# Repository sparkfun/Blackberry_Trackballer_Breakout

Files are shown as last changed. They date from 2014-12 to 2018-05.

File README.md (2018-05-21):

**NOTE:** *This product has been retired from our catalog. If you are looking for more up-to-date info, please check out some of these resources to see how other users are still hacking and improving on this product.*
* *[SparkFun Forum](https://forum.sparkfun.com/)*
* *[Comments Here on GitHub](https://github.com/sparkfun/Blackberry_Trackballer_Breakout/issues)*
* *[IRC Channel](https://www.sparkfun.com/news/263)*

SparkFun BlackBerry Trackballer Breakout
========================================

SparkFun BlackBerry Trackballer Breakout

[*SparkFun BlackBerry Trackballer Breakout (COM-13169)*](https://www.sparkfun.com/products/13169)

The SparkFun BlackBerry Trackballer Breakout gives you easy access to a trackball which measures up, down, left, and right movements, clicks on the board, as well as adding a bit of flair to your project with four built-in LEDs. The trackballer breakout can be hooked into an Arduino compatible device to provide you with an intuitive direction controller.

Repository Contents
-------------------
 
* **/Firmware** - Example Arduino code 
* **/Hardware** - Eagle design files (.brd, .sch) for the main PCB, and the mounting PCB. 
* **/Production** - Production panel files (.brd) for the main PCB. The mounting PCB did not need to be panelized. 

Documentation
--------------
* **[Hookup Guide](https://learn.sparkfun.com/tutorials/blackberry-trackballer-breakout-hookup-guide)** - Basic hookup guide for the Trackballer Breakout.
* **[SparkFun Fritzing repo](https://github.com/sparkfun/Fritzing_Parts)** - Fritzing diagrams for SparkFun products.
* **[SparkFun 3D Model repo](https://github.com/sparkfun/3D_Models)** - 3D models of SparkFun products. 

Product Versions
----------------
* [COM-13169](https://www.sparkfun.com/products/13169)- Version 1.3. Retired.
* [COM-09320](https://www.sparkfun.com/products/9320)- Version 1.2. Retired. 

License Information
-------------------
This product is _**open source**_! 

The **hardware** is released under [Creative Commons ShareAlike 4.0 International](https://creativecommons.org/licenses/by-sa/4.0/).

The **code** is beerware; if you see me (or any other SparkFun employee) at the local, and you've found our code helpful, please buy us a round!

Please use, reuse, and modify these files as you see fit. Please maintain attribution to SparkFun Electronics and release anything derivative under the same license.

Distributed as-is; no warranty is given.

- Your friends at SparkFun.

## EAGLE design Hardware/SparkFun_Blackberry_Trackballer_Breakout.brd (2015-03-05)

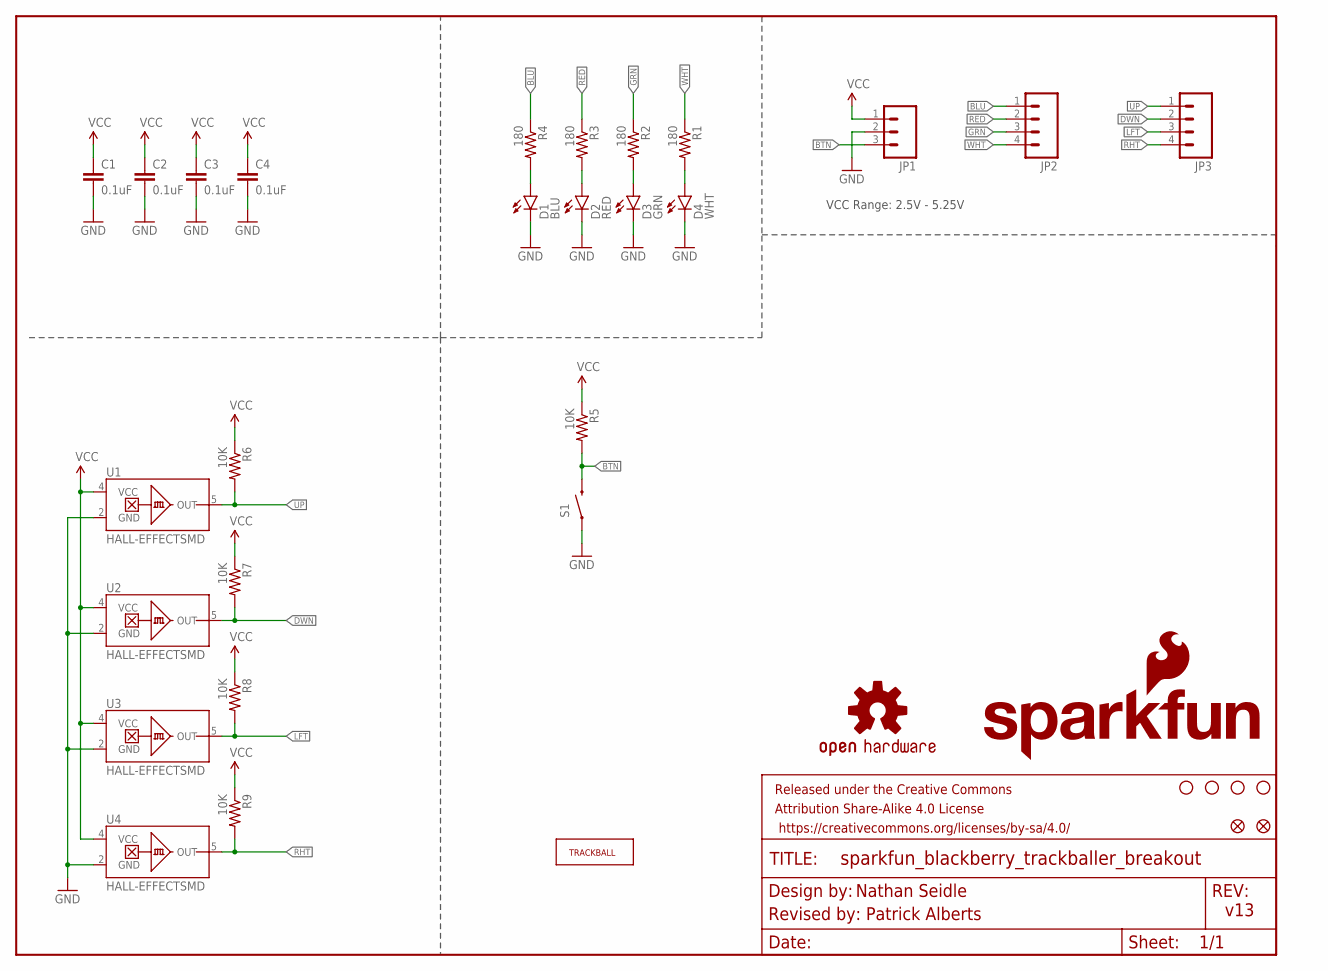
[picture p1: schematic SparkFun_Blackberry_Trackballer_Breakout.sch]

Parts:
C1, C2, C3, C4: 0.1uF; 0603-CAP
D1: BLU; LED-0603
D2: RED; LED-0603
D3: GRN; LED-0603
D4: WHT; LED-0603
E$1, E$2: FIDUCIAL1X2; FIDUCIAL-1X2
FRAME1: FRAME-LETTER; CREATIVE_COMMONS
JP1: M03PTH; 1X03
JP2, JP3: M04PTH; 1X04
LOGO1: SFE_LOGO_NAME_FLAME.2_INCH; SFE_LOGO_NAME_FLAME_.2
LOGO2: OSHW-LOGOS; OSHW-LOGO-S
R1, R2, R3, R4: 180; 0603-RES
R5, R6, R7, R8, R9: 10K; 0603-RES
S1: SWITCH-MOMENTARY-2SMD-2; TACTILE_SWITCH_SMD-2
U1, U2, U3, U4: HALL-EFFECTSMD; SC70
U$1, U$8, U$11, U$14: STAND-OFF
U$3: TRACKBALLMECH; TRACKBALL

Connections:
BLU: JP2.1, R4.1
BTN: JP1.3, R5.2, S1.1 (2)
DWN: JP3.2, R7.2, U2.5 (OUT)
GND: C1.2, C2.2, C3.2, C4.2, D1.C, D2.C, D3.C, D4.C, JP1.2, S1.2 (1), U1.2 (GND), U2.2 (GND), U3.2 (GND), U4.2 (GND)
GRN: JP2.3, R2.1
LFT: JP3.3, R8.2, U3.5 (OUT)
unnamed: D3.A, R2.2
unnamed: D2.A, R3.2
unnamed: D1.A, R4.2
unnamed: D4.A, R1.2
RED: JP2.2, R3.1
RHT: JP3.4, R9.2, U4.5 (OUT)
UP: JP3.1, R6.2, U1.5 (OUT)
VCC: C1.1, C2.1, C3.1, C4.1, JP1.1, R5.1, R6.1, R7.1, R8.1, R9.1, U1.4 (VCC), U2.4 (VCC), U3.4 (VCC), U4.4 (VCC)
WHT: JP2.4, R1.1

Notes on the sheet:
v13
Nathan Seidle
Revised by: Patrick Alberts
VCC Range: 2.5V - 5.25V

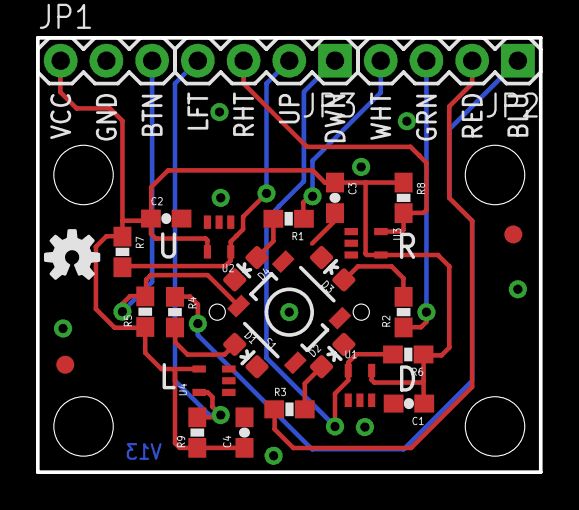
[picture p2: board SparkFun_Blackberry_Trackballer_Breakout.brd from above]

Board: 2 copper layers, 27.9 x 24.1 mm, 35 parts (1 on the bottom side), 15 nets.

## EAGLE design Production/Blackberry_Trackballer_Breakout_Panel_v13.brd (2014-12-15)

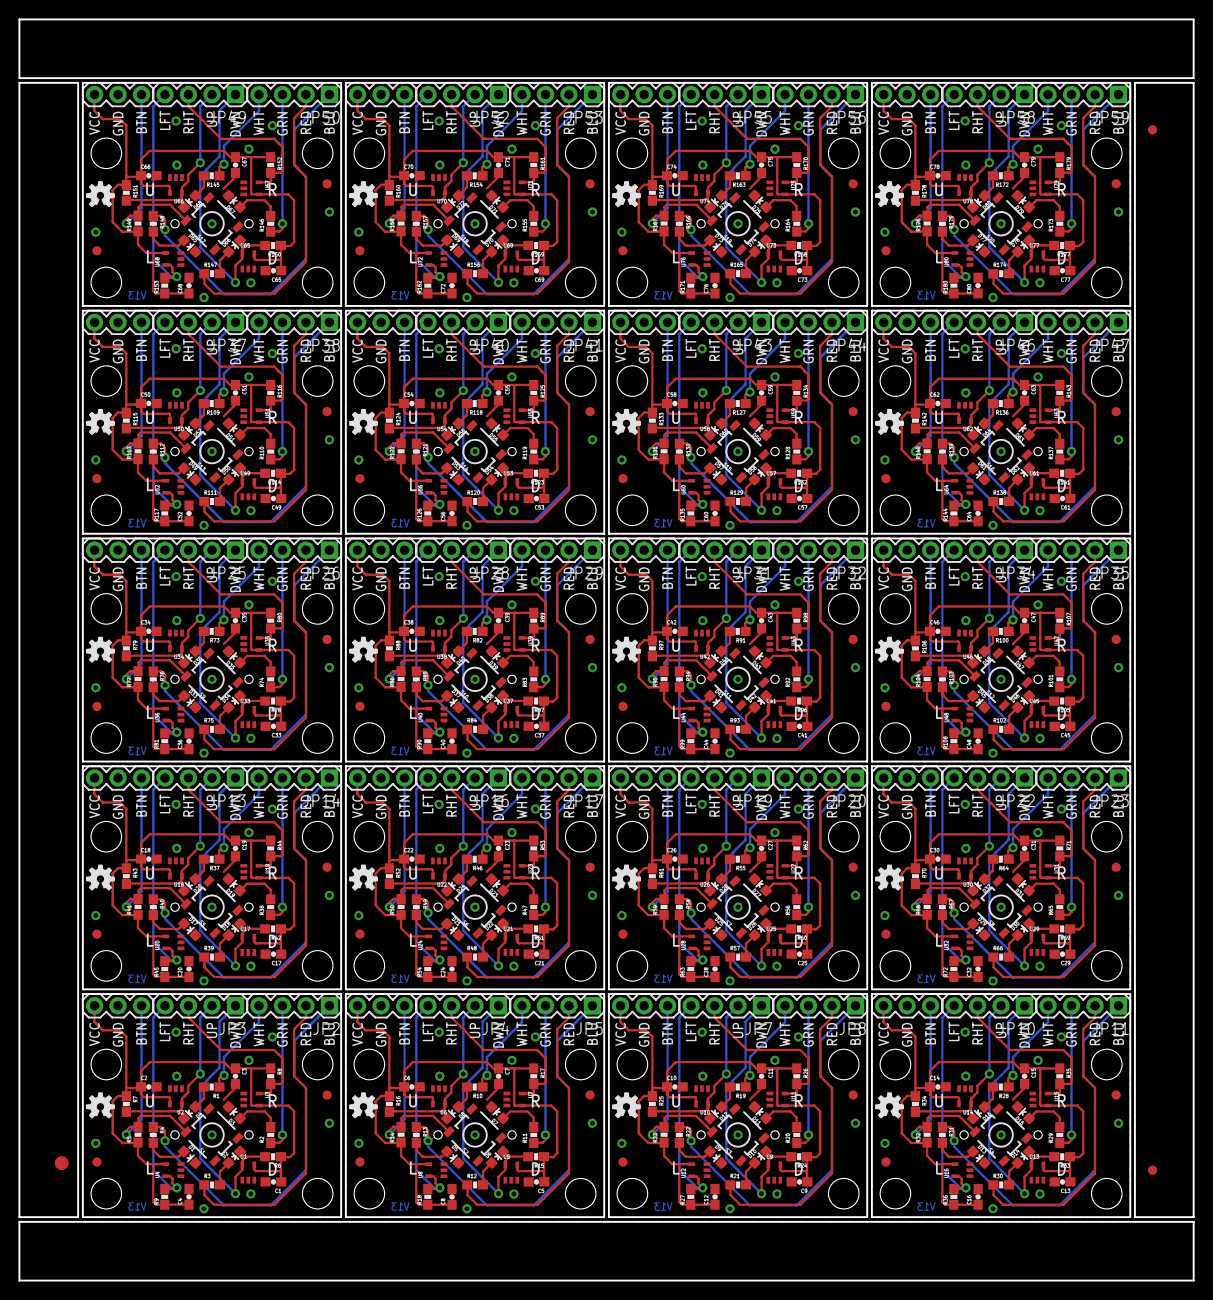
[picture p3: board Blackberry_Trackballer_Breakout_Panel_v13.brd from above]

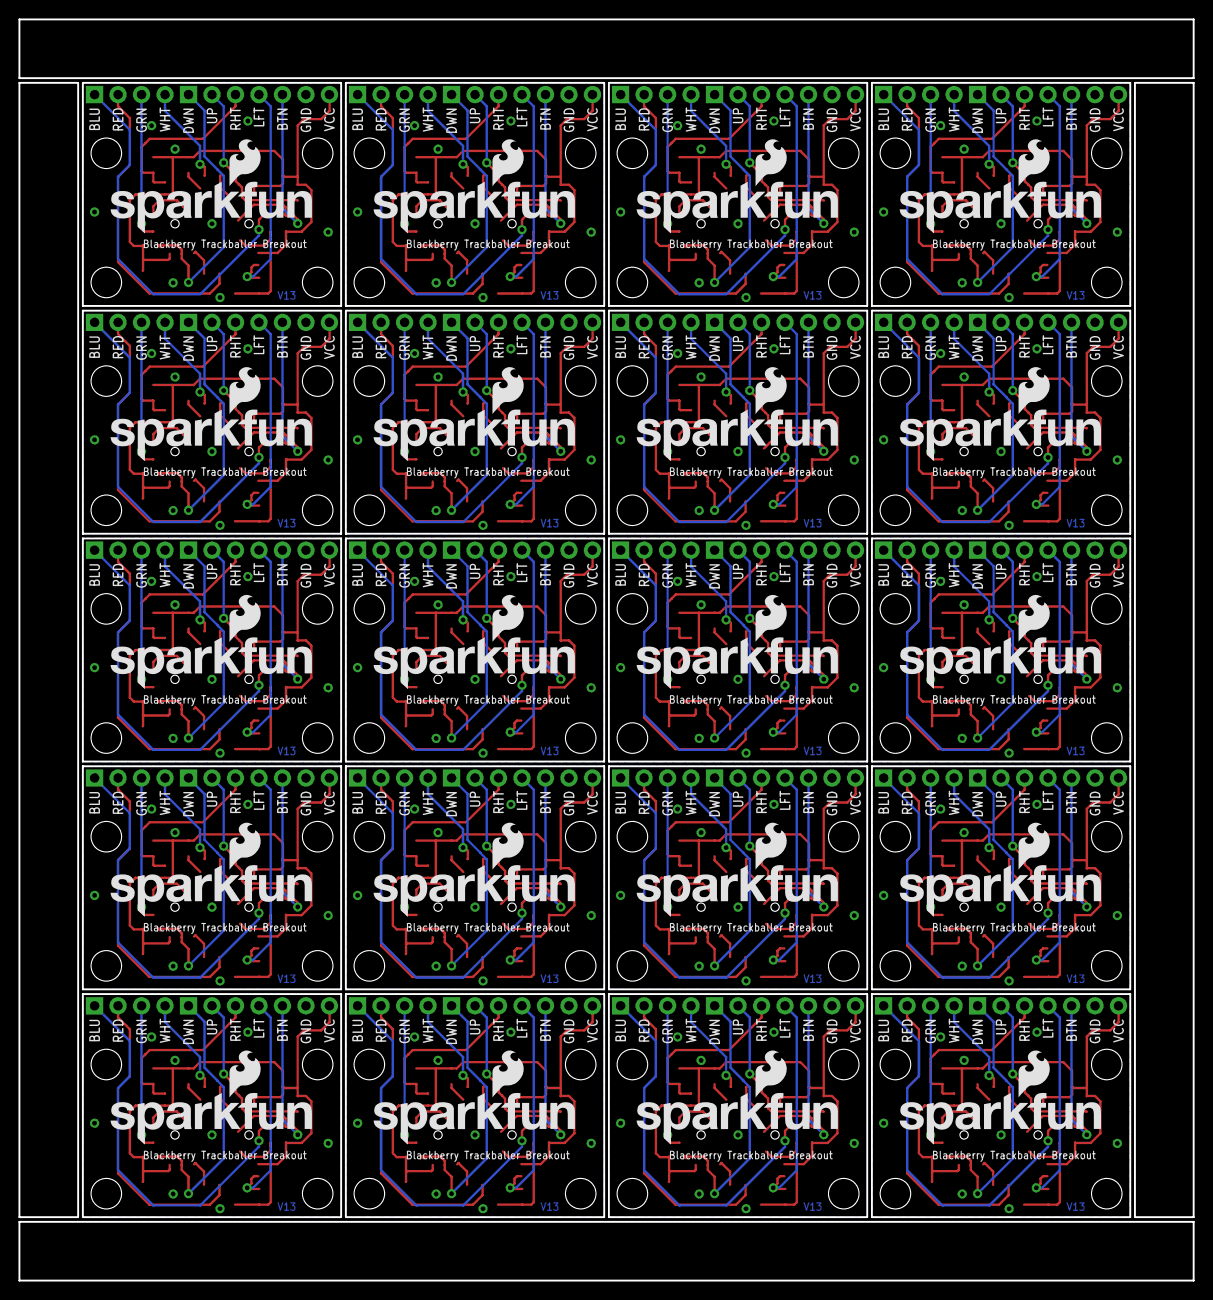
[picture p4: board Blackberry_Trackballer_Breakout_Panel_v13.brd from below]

Board: 2 copper layers, 127.0 x 136.4 mm, 683 parts (20 on the bottom side), 300 nets.

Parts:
C1, C2, C3, C4, C5, C6, C7, C8, C9, C10, C11, C12, C13, C14, C15, C16, C17, C18, C19, C20, C21, C22, C23, C24, C25, C26, C27, C28, C29, C30, C31, C32, C33, C34, C35, C36, C37, C38, C39, C40, C41, C42, C43, C44, C45, C46, C47, C48, C49, C50, C51, C52, C53, C54, C55, C56, C57, C58, C59, C60, C61, C62, C63, C64, C65, C66, C67, C68, C69, C70, C71, C72, C73, C74, C75, C76, C77, C78, C79, C80: 0.1uF; 0603-CAP
D1, D5, D9, D13, D17, D21, D25, D29, D33, D37, D41, D45, D49, D53, D57, D61, D65, D69, D73, D77: BLU; LED-0603
D2, D6, D10, D14, D18, D22, D26, D30, D34, D38, D42, D46, D50, D54, D58, D62, D66, D70, D74, D78: RED; LED-0603
D3, D7, D11, D15, D19, D23, D27, D31, D35, D39, D43, D47, D51, D55, D59, D63, D67, D71, D75, D79: GRN; LED-0603
D4, D8, D12, D16, D20, D24, D28, D32, D36, D40, D44, D48, D52, D56, D60, D64, D68, D72, D76, D80: WHT; LED-0603
E$1, E$2, E$3, E$4, E$5, E$6, E$7, E$8, E$9, E$10, E$11, E$12, E$13, E$14, E$15, E$16, E$17, E$18, E$19, E$20, E$21, E$22, E$23, E$24, E$25, E$26, E$27, E$28, E$29, E$30, E$31, E$32, E$33, E$34, E$35, E$36, E$37, E$38, E$39, E$40: FIDUCIAL1X2; FIDUCIAL-1X2
E$41: FIDUCIAL-1.5X3
E$44, E$45: FIDUCIAL-1X2
JP1, JP6, JP9, JP12, JP15, JP18, JP21, JP24, JP27, JP30, JP33, JP36, JP39, JP42, JP45, JP48, JP51, JP54, JP57, JP60: 1X03
JP2, JP3, JP4, JP5, JP7, JP8, JP10, JP11, JP13, JP14, JP16, JP17, JP19, JP20, JP22, JP23, JP25, JP26, JP28, JP29, JP31, JP32, JP34, JP35, JP37, JP38, JP40, JP41, JP43, JP44, JP46, JP47, JP49, JP50, JP52, JP53, JP55, JP56, JP58, JP59: 1X04
LOGO1, LOGO3, LOGO5, LOGO7, LOGO9, LOGO11, LOGO13, LOGO15, LOGO17, LOGO19, LOGO21, LOGO23, LOGO25, LOGO27, LOGO29, LOGO31, LOGO33, LOGO35, LOGO37, LOGO39: SFE_LOGO_NAME_FLAME.2_INCH; SFE_LOGO_NAME_FLAME_.2
LOGO2, LOGO4, LOGO6, LOGO8, LOGO10, LOGO12, LOGO14, LOGO16, LOGO18, LOGO20, LOGO22, LOGO24, LOGO26, LOGO28, LOGO30, LOGO32, LOGO34, LOGO36, LOGO38, LOGO40: OSHW-LOGOS; OSHW-LOGO-S
R1, R2, R3, R4, R10, R11, R12, R13, R19, R20, R21, R22, R28, R29, R30, R31, R37, R38, R39, R40, R46, R47, R48, R49, R55, R56, R57, R58, R64, R65, R66, R67, R73, R74, R75, R76, R82, R83, R84, R85, R91, R92, R93, R94, R100, R101, R102, R103, R109, R110, R111, R112, R118, R119, R120, R121, R127, R128, R129, R130, R136, R137, R138, R139, R145, R146, R147, R148, R154, R155, R156, R157, R163, R164, R165, R166, R172, R173, R174, R175: 180; 0603-RES
R5, R6, R7, R8, R9, R14, R15, R16, R17, R18, R23, R24, R25, R26, R27, R32, R33, R34, R35, R36, R41, R42, R43, R44, R45, R50, R51, R52, R53, R54, R59, R60, R61, R62, R63, R68, R69, R70, R71, R72, R77, R78, R79, R80, R81, R86, R87, R88, R89, R90, R95, R96, R97, R98, R99, R104, R105, R106, R107, R108, R113, R114, R115, R116, R117, R122, R123, R124, R125, R126, R131, R132, R133, R134, R135, R140, R141, R142, R143, R144, R149, R150, R151, R152, R153, R158, R159, R160, R161, R162, R167, R168, R169, R170, R171, R176, R177, R178, R179, R180: 10K; 0603-RES
S1, S2, S3, S4, S5, S6, S7, S8, S9, S10, S11, S12, S13, S14, S15, S16, S17, S18, S19, S20: SWITCH-MOMENTARY-2SMD-2; TACTILE_SWITCH_SMD-2
U1, U2, U3, U4, U5, U6, U7, U8, U9, U10, U11, U12, U13, U14, U15, U16, U17, U18, U19, U20, U21, U22, U23, U24, U25, U26, U27, U28, U29, U30, U31, U32, U33, U34, U35, U36, U37, U38, U39, U40, U41, U42, U43, U44, U45, U46, U47, U48, U49, U50, U51, U52, U53, U54, U55, U56, U57, U58, U59, U60, U61, U62, U63, U64, U65, U66, U67, U68, U69, U70, U71, U72, U73, U74, U75, U76, U77, U78, U79, U80: HALL-EFFECTSMD; SC70
U$1, U$2, U$4, U$5, U$6, U$8, U$9, U$10, U$11, U$12, U$13, U$14, U$16, U$17, U$18, U$19, U$21, U$22, U$23, U$24, U$26, U$27, U$28, U$29, U$31, U$32, U$33, U$34, U$36, U$37, U$38, U$39, U$41, U$42, U$43, U$44, U$46, U$47, U$48, U$49, U$51, U$52, U$53, U$54, U$56, U$57, U$58, U$59, U$61, U$62, U$63, U$64, U$66, U$67, U$68, U$69, U$71, U$72, U$73, U$74, U$76, U$77, U$78, U$79, U$81, U$82, U$83, U$84, U$86, U$87, U$88, U$89, U$91, U$92, U$93, U$94, U$96, U$97, U$98, U$99: STAND-OFF
U$3, U$7, U$15, U$20, U$25, U$30, U$35, U$40, U$45, U$50, U$55, U$60, U$65, U$70, U$75, U$80, U$85, U$90, U$95, U$100: TRACKBALLMECH; TRACKBALL

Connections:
BLU: JP2.1, R4.1
BLU1: JP5.1, R13.1
BLU2: JP8.1, R22.1
BLU3: JP11.1, R31.1
BLU4: JP14.1, R40.1
BLU5: JP17.1, R49.1
BLU6: JP20.1, R58.1
BLU7: JP23.1, R67.1
BLU8: JP26.1, R76.1
BLU9: JP29.1, R85.1
BLU10: JP32.1, R94.1
BLU11: JP35.1, R103.1
BLU12: JP38.1, R112.1
BLU13: JP41.1, R121.1
BLU14: JP44.1, R130.1
BLU15: JP47.1, R139.1
BLU16: JP50.1, R148.1
BLU17: JP53.1, R157.1
BLU18: JP56.1, R166.1
BLU19: JP59.1, R175.1
BTN: JP1.3, R5.2, S1.1
BTN1: JP6.3, R14.2, S2.1
BTN2: JP9.3, R23.2, S3.1
BTN3: JP12.3, R32.2, S4.1
BTN4: JP15.3, R41.2, S5.1
BTN5: JP18.3, R50.2, S6.1
BTN6: JP21.3, R59.2, S7.1
BTN7: JP24.3, R68.2, S8.1
BTN8: JP27.3, R77.2, S9.1
BTN9: JP30.3, R86.2, S10.1
BTN10: JP33.3, R95.2, S11.1
BTN11: JP36.3, R104.2, S12.1
BTN12: JP39.3, R113.2, S13.1
BTN13: JP42.3, R122.2, S14.1
BTN14: JP45.3, R131.2, S15.1
BTN15: JP48.3, R140.2, S16.1
BTN16: JP51.3, R149.2, S17.1
BTN17: JP54.3, R158.2, S18.1
BTN18: JP57.3, R167.2, S19.1
BTN19: JP60.3, R176.2, S20.1
DWN: JP3.2, R7.2, U2.5
DWN1: JP4.2, R16.2, U6.5
DWN2: JP7.2, R25.2, U10.5
DWN3: JP10.2, R34.2, U14.5
DWN4: JP13.2, R43.2, U18.5
DWN5: JP16.2, R52.2, U22.5
DWN6: JP19.2, R61.2, U26.5
DWN7: JP22.2, R70.2, U30.5
DWN8: JP25.2, R79.2, U34.5
DWN9: JP28.2, R88.2, U38.5
DWN10: JP31.2, R97.2, U42.5
DWN11: JP34.2, R106.2, U46.5
DWN12: JP37.2, R115.2, U50.5
DWN13: JP40.2, R124.2, U54.5
DWN14: JP43.2, R133.2, U58.5
DWN15: JP46.2, R142.2, U62.5
DWN16: JP49.2, R151.2, U66.5
DWN17: JP52.2, R160.2, U70.5
DWN18: JP55.2, R169.2, U74.5
DWN19: JP58.2, R178.2, U78.5
GND: C1.2, C2.2, C3.2, C4.2, D1.C, D2.C, D3.C, D4.C, JP1.2, S1.2, U1.2, U2.2, U3.2, U4.2
GND1: C5.2, C6.2, C7.2, C8.2, D5.C, D6.C, D7.C, D8.C, JP6.2, S2.2, U5.2, U6.2, U7.2, U8.2
GND2: C9.2, C10.2, C11.2, C12.2, D9.C, D10.C, D11.C, D12.C, JP9.2, S3.2, U9.2, U10.2, U11.2, U12.2
GND3: C13.2, C14.2, C15.2, C16.2, D13.C, D14.C, D15.C, D16.C, JP12.2, S4.2, U13.2, U14.2, U15.2, U16.2
GND4: C17.2, C18.2, C19.2, C20.2, D17.C, D18.C, D19.C, D20.C, JP15.2, S5.2, U17.2, U18.2, U19.2, U20.2
GND5: C21.2, C22.2, C23.2, C24.2, D21.C, D22.C, D23.C, D24.C, JP18.2, S6.2, U21.2, U22.2, U23.2, U24.2
GND6: C25.2, C26.2, C27.2, C28.2, D25.C, D26.C, D27.C, D28.C, JP21.2, S7.2, U25.2, U26.2, U27.2, U28.2
GND7: C29.2, C30.2, C31.2, C32.2, D29.C, D30.C, D31.C, D32.C, JP24.2, S8.2, U29.2, U30.2, U31.2, U32.2
GND8: C33.2, C34.2, C35.2, C36.2, D33.C, D34.C, D35.C, D36.C, JP27.2, S9.2, U33.2, U34.2, U35.2, U36.2
GND9: C37.2, C38.2, C39.2, C40.2, D37.C, D38.C, D39.C, D40.C, JP30.2, S10.2, U37.2, U38.2, U39.2, U40.2
GND10: C41.2, C42.2, C43.2, C44.2, D41.C, D42.C, D43.C, D44.C, JP33.2, S11.2, U41.2, U42.2, U43.2, U44.2
GND11: C45.2, C46.2, C47.2, C48.2, D45.C, D46.C, D47.C, D48.C, JP36.2, S12.2, U45.2, U46.2, U47.2, U48.2
GND12: C49.2, C50.2, C51.2, C52.2, D49.C, D50.C, D51.C, D52.C, JP39.2, S13.2, U49.2, U50.2, U51.2, U52.2
GND13: C53.2, C54.2, C55.2, C56.2, D53.C, D54.C, D55.C, D56.C, JP42.2, S14.2, U53.2, U54.2, U55.2, U56.2
GND14: C57.2, C58.2, C59.2, C60.2, D57.C, D58.C, D59.C, D60.C, JP45.2, S15.2, U57.2, U58.2, U59.2, U60.2
GND15: C61.2, C62.2, C63.2, C64.2, D61.C, D62.C, D63.C, D64.C, JP48.2, S16.2, U61.2, U62.2, U63.2, U64.2
GND16: C65.2, C66.2, C67.2, C68.2, D65.C, D66.C, D67.C, D68.C, JP51.2, S17.2, U65.2, U66.2, U67.2, U68.2
GND17: C69.2, C70.2, C71.2, C72.2, D69.C, D70.C, D71.C, D72.C, JP54.2, S18.2, U69.2, U70.2, U71.2, U72.2
GND18: C73.2, C74.2, C75.2, C76.2, D73.C, D74.C, D75.C, D76.C, JP57.2, S19.2, U73.2, U74.2, U75.2, U76.2
GND19: C77.2, C78.2, C79.2, C80.2, D77.C, D78.C, D79.C, D80.C, JP60.2, S20.2, U77.2, U78.2, U79.2, U80.2
GRN: JP2.3, R2.1
GRN1: JP5.3, R11.1
GRN2: JP8.3, R20.1
GRN3: JP11.3, R29.1
GRN4: JP14.3, R38.1
GRN5: JP17.3, R47.1
GRN6: JP20.3, R56.1
GRN7: JP23.3, R65.1
GRN8: JP26.3, R74.1
GRN9: JP29.3, R83.1
GRN10: JP32.3, R92.1
GRN11: JP35.3, R101.1
GRN12: JP38.3, R110.1
GRN13: JP41.3, R119.1
GRN14: JP44.3, R128.1
GRN15: JP47.3, R137.1
GRN16: JP50.3, R146.1
GRN17: JP53.3, R155.1
GRN18: JP56.3, R164.1
GRN19: JP59.3, R173.1
LFT: JP3.3, R8.2, U3.5
LFT1: JP4.3, R17.2, U7.5
LFT2: JP7.3, R26.2, U11.5
LFT3: JP10.3, R35.2, U15.5
LFT4: JP13.3, R44.2, U19.5
LFT5: JP16.3, R53.2, U23.5
LFT6: JP19.3, R62.2, U27.5
LFT7: JP22.3, R71.2, U31.5
LFT8: JP25.3, R80.2, U35.5
LFT9: JP28.3, R89.2, U39.5
LFT10: JP31.3, R98.2, U43.5
LFT11: JP34.3, R107.2, U47.5
LFT12: JP37.3, R116.2, U51.5
LFT13: JP40.3, R125.2, U55.5
LFT14: JP43.3, R134.2, U59.5
LFT15: JP46.3, R143.2, U63.5
LFT16: JP49.3, R152.2, U67.5
LFT17: JP52.3, R161.2, U71.5
LFT18: JP55.3, R170.2, U75.5
LFT19: JP58.3, R179.2, U79.5
unnamed: D3.A, R2.2
unnamed: D2.A, R3.2
unnamed: D1.A, R4.2
unnamed: D4.A, R1.2
unnamed: D7.A, R11.2
unnamed: D6.A, R12.2
unnamed: D5.A, R13.2
unnamed: D8.A, R10.2
unnamed: D11.A, R20.2
unnamed: D10.A, R21.2
unnamed: D9.A, R22.2
unnamed: D12.A, R19.2
unnamed: D15.A, R29.2
unnamed: D14.A, R30.2
unnamed: D13.A, R31.2
unnamed: D16.A, R28.2
unnamed: D19.A, R38.2
unnamed: D18.A, R39.2
unnamed: D17.A, R40.2
unnamed: D20.A, R37.2
unnamed: D23.A, R47.2
unnamed: D22.A, R48.2
unnamed: D21.A, R49.2
unnamed: D24.A, R46.2
unnamed: D27.A, R56.2
unnamed: D26.A, R57.2
unnamed: D25.A, R58.2
unnamed: D28.A, R55.2
unnamed: D31.A, R65.2
unnamed: D30.A, R66.2
unnamed: D29.A, R67.2
unnamed: D32.A, R64.2
unnamed: D35.A, R74.2
unnamed: D34.A, R75.2
unnamed: D33.A, R76.2
unnamed: D36.A, R73.2
unnamed: D39.A, R83.2
unnamed: D38.A, R84.2
unnamed: D37.A, R85.2
unnamed: D40.A, R82.2
unnamed: D43.A, R92.2
unnamed: D42.A, R93.2
unnamed: D41.A, R94.2
unnamed: D44.A, R91.2
unnamed: D47.A, R101.2
unnamed: D46.A, R102.2
unnamed: D45.A, R103.2
unnamed: D48.A, R100.2
unnamed: D51.A, R110.2
unnamed: D50.A, R111.2
unnamed: D49.A, R112.2
unnamed: D52.A, R109.2
unnamed: D55.A, R119.2
unnamed: D54.A, R120.2
unnamed: D53.A, R121.2
unnamed: D56.A, R118.2
unnamed: D59.A, R128.2
unnamed: D58.A, R129.2
unnamed: D57.A, R130.2
unnamed: D60.A, R127.2
unnamed: D63.A, R137.2
unnamed: D62.A, R138.2
unnamed: D61.A, R139.2
unnamed: D64.A, R136.2
unnamed: D67.A, R146.2
unnamed: D66.A, R147.2
unnamed: D65.A, R148.2
unnamed: D68.A, R145.2
unnamed: D71.A, R155.2
unnamed: D70.A, R156.2
unnamed: D69.A, R157.2
unnamed: D72.A, R154.2
unnamed: D75.A, R164.2
unnamed: D74.A, R165.2
unnamed: D73.A, R166.2
unnamed: D76.A, R163.2
unnamed: D79.A, R173.2
unnamed: D78.A, R174.2
unnamed: D77.A, R175.2
unnamed: D80.A, R172.2
RED: JP2.2, R3.1
RED1: JP5.2, R12.1
RED2: JP8.2, R21.1
RED3: JP11.2, R30.1
RED4: JP14.2, R39.1
RED5: JP17.2, R48.1
RED6: JP20.2, R57.1
RED7: JP23.2, R66.1
RED8: JP26.2, R75.1
RED9: JP29.2, R84.1
RED10: JP32.2, R93.1
RED11: JP35.2, R102.1
RED12: JP38.2, R111.1
RED13: JP41.2, R120.1
RED14: JP44.2, R129.1
RED15: JP47.2, R138.1
RED16: JP50.2, R147.1
RED17: JP53.2, R156.1
RED18: JP56.2, R165.1
RED19: JP59.2, R174.1
RHT: JP3.4, R9.2, U4.5
RHT1: JP4.4, R18.2, U8.5
RHT2: JP7.4, R27.2, U12.5
RHT3: JP10.4, R36.2, U16.5
RHT4: JP13.4, R45.2, U20.5
RHT5: JP16.4, R54.2, U24.5
RHT6: JP19.4, R63.2, U28.5
RHT7: JP22.4, R72.2, U32.5
RHT8: JP25.4, R81.2, U36.5
RHT9: JP28.4, R90.2, U40.5
RHT10: JP31.4, R99.2, U44.5
RHT11: JP34.4, R108.2, U48.5
RHT12: JP37.4, R117.2, U52.5
RHT13: JP40.4, R126.2, U56.5
RHT14: JP43.4, R135.2, U60.5
RHT15: JP46.4, R144.2, U64.5
RHT16: JP49.4, R153.2, U68.5
RHT17: JP52.4, R162.2, U72.5
RHT18: JP55.4, R171.2, U76.5
RHT19: JP58.4, R180.2, U80.5
UP: JP3.1, R6.2, U1.5
UP1: JP4.1, R15.2, U5.5
UP2: JP7.1, R24.2, U9.5
UP3: JP10.1, R33.2, U13.5
UP4: JP13.1, R42.2, U17.5
UP5: JP16.1, R51.2, U21.5
UP6: JP19.1, R60.2, U25.5
UP7: JP22.1, R69.2, U29.5
UP8: JP25.1, R78.2, U33.5
UP9: JP28.1, R87.2, U37.5
UP10: JP31.1, R96.2, U41.5
UP11: JP34.1, R105.2, U45.5
UP12: JP37.1, R114.2, U49.5
UP13: JP40.1, R123.2, U53.5
UP14: JP43.1, R132.2, U57.5
UP15: JP46.1, R141.2, U61.5
UP16: JP49.1, R150.2, U65.5
UP17: JP52.1, R159.2, U69.5
UP18: JP55.1, R168.2, U73.5
UP19: JP58.1, R177.2, U77.5
VCC: C1.1, C2.1, C3.1, C4.1, JP1.1, R5.1, R6.1, R7.1, R8.1, R9.1, U1.4, U2.4, U3.4, U4.4
VCC1: C5.1, C6.1, C7.1, C8.1, JP6.1, R14.1, R15.1, R16.1, R17.1, R18.1, U5.4, U6.4, U7.4, U8.4
VCC2: C9.1, C10.1, C11.1, C12.1, JP9.1, R23.1, R24.1, R25.1, R26.1, R27.1, U9.4, U10.4, U11.4, U12.4
VCC3: C13.1, C14.1, C15.1, C16.1, JP12.1, R32.1, R33.1, R34.1, R35.1, R36.1, U13.4, U14.4, U15.4, U16.4
VCC4: C17.1, C18.1, C19.1, C20.1, JP15.1, R41.1, R42.1, R43.1, R44.1, R45.1, U17.4, U18.4, U19.4, U20.4
VCC5: C21.1, C22.1, C23.1, C24.1, JP18.1, R50.1, R51.1, R52.1, R53.1, R54.1, U21.4, U22.4, U23.4, U24.4
VCC6: C25.1, C26.1, C27.1, C28.1, JP21.1, R59.1, R60.1, R61.1, R62.1, R63.1, U25.4, U26.4, U27.4, U28.4
VCC7: C29.1, C30.1, C31.1, C32.1, JP24.1, R68.1, R69.1, R70.1, R71.1, R72.1, U29.4, U30.4, U31.4, U32.4
VCC8: C33.1, C34.1, C35.1, C36.1, JP27.1, R77.1, R78.1, R79.1, R80.1, R81.1, U33.4, U34.4, U35.4, U36.4
VCC9: C37.1, C38.1, C39.1, C40.1, JP30.1, R86.1, R87.1, R88.1, R89.1, R90.1, U37.4, U38.4, U39.4, U40.4
VCC10: C41.1, C42.1, C43.1, C44.1, JP33.1, R95.1, R96.1, R97.1, R98.1, R99.1, U41.4, U42.4, U43.4, U44.4
VCC11: C45.1, C46.1, C47.1, C48.1, JP36.1, R104.1, R105.1, R106.1, R107.1, R108.1, U45.4, U46.4, U47.4, U48.4
VCC12: C49.1, C50.1, C51.1, C52.1, JP39.1, R113.1, R114.1, R115.1, R116.1, R117.1, U49.4, U50.4, U51.4, U52.4
VCC13: C53.1, C54.1, C55.1, C56.1, JP42.1, R122.1, R123.1, R124.1, R125.1, R126.1, U53.4, U54.4, U55.4, U56.4
VCC14: C57.1, C58.1, C59.1, C60.1, JP45.1, R131.1, R132.1, R133.1, R134.1, R135.1, U57.4, U58.4, U59.4, U60.4
VCC15: C61.1, C62.1, C63.1, C64.1, JP48.1, R140.1, R141.1, R142.1, R143.1, R144.1, U61.4, U62.4, U63.4, U64.4
VCC16: C65.1, C66.1, C67.1, C68.1, JP51.1, R149.1, R150.1, R151.1, R152.1, R153.1, U65.4, U66.4, U67.4, U68.4
VCC17: C69.1, C70.1, C71.1, C72.1, JP54.1, R158.1, R159.1, R160.1, R161.1, R162.1, U69.4, U70.4, U71.4, U72.4
VCC18: C73.1, C74.1, C75.1, C76.1, JP57.1, R167.1, R168.1, R169.1, R170.1, R171.1, U73.4, U74.4, U75.4, U76.4
VCC19: C77.1, C78.1, C79.1, C80.1, JP60.1, R176.1, R177.1, R178.1, R179.1, R180.1, U77.4, U78.4, U79.4, U80.4
WHT: JP2.4, R1.1
WHT1: JP5.4, R10.1
WHT2: JP8.4, R19.1
WHT3: JP11.4, R28.1
WHT4: JP14.4, R37.1
WHT5: JP17.4, R46.1
WHT6: JP20.4, R55.1
WHT7: JP23.4, R64.1
WHT8: JP26.4, R73.1
WHT9: JP29.4, R82.1
WHT10: JP32.4, R91.1
WHT11: JP35.4, R100.1
WHT12: JP38.4, R109.1
WHT13: JP41.4, R118.1
WHT14: JP44.4, R127.1
WHT15: JP47.4, R136.1
WHT16: JP50.4, R145.1
WHT17: JP53.4, R154.1
WHT18: JP56.4, R163.1
WHT19: JP59.4, R172.1

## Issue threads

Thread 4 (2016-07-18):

make move sensitive

hackwin, 2016-07-18:
is there a way to increase the sensitivity so a small movement on the trackball triggers a large change in up/down left/right?

ToniCorinne, 2016-07-19:
If you simply want a larger change in up/down/left/right, you can update the position variables to scale by more than 1 unit with each register of a change in the code.

For example:
     ` if (mouse_Lft > 0)
  {
    x_position= --x_position;
}`

could be changed to
` if (mouse_Lft > 0)
  {
    x_position= x_position-8;
}`
if you wanted to scale the positioning to change 8x more quickly. Otherwise, you'd need to be working on a microcontroller that you could map up/down/left/right to interrupt pins and play with the sensitivity and scaling from there.

hackwin, 2016-07-25:
thanks, i did using an arduino mega: https://codebender.cc/sketch:348904

the module worked as a computer mouse by using Processing/Java to mouse the mouse.

http://pastebin.com/6W6m0gQG

bboyho, 2018-05-21:
It looks like this issue was addressed. I am closing it outl. =)

Closed 2018-05-21.

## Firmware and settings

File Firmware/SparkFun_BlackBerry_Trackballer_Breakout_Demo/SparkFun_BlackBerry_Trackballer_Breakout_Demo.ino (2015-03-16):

/**************************************************************************
SparkFun BlackBerry Trackballer Breakout Demo
Toni Klopfenstein @ SparkFun Electronics
March 2015
https://github.com/sparkfun/Blackberry_Trackballer_Breakout
This demo shows all the basic functionality of the SparkFun BlackBerry Trackballer Breakout (https://www.sparkfun.com/products/13169).
Development environment specifics:
Developed in Arduino 1.6.0
This code is beerware; if you see me (or any other SparkFun employee) at the local, and you've found our code helpful, please buy us a round!
Distributed as-is; no warranty is given.
***************************************************************************/

//Define Trackballer Breakout pin connections to Arduino
#define Btn 2
#define Lft 3
#define Rht 4
#define Up 5
#define Dwn 6
#define WHT_LED 7
#define GRN_LED 8
#define RED_LED 9
#define BLU_LED 10

//Define variables used in sketch
int buttonClick;
unsigned long mouse_Lft;
unsigned long mouse_Rht;
unsigned long mouse_Up;
unsigned long mouse_Dwn;
int x_position;
int y_position;

/*********************Setup Loop*************************/
void setup() {
  
  //Define pin functionality on the Arduino
  pinMode(Btn, INPUT);
  pinMode(Lft, INPUT);
  pinMode(Rht, INPUT);
  pinMode(Up, INPUT);
  pinMode(Dwn, INPUT);
  pinMode(WHT_LED, OUTPUT);
  pinMode(GRN_LED, OUTPUT);
  pinMode(RED_LED, OUTPUT);
  pinMode(BLU_LED, OUTPUT);
  
  //Pull LED pins low to prevent flickering
  digitalWrite(WHT_LED, LOW);
  digitalWrite(GRN_LED, LOW);
  digitalWrite(RED_LED, LOW);
  digitalWrite(BLU_LED, LOW);
  
  //Start Serial port for debugging. 
  Serial.begin(9600); 
  Serial.println("Begin Trackballer Demo");
 
  //Demo each LED by turning them on individually for one second. 
  Serial.println("Turn on LEDs individually");
  digitalWrite(WHT_LED, HIGH);
  delay(1000);
  digitalWrite(WHT_LED, LOW);
  
  digitalWrite(GRN_LED, HIGH);
  delay(1000);
  digitalWrite(GRN_LED, LOW);
  
  digitalWrite(RED_LED, HIGH);
  delay(1000);
  digitalWrite(RED_LED, LOW);
  
  digitalWrite(BLU_LED, HIGH);
  delay(1000);
  digitalWrite(BLU_LED, LOW);
  
  Serial.println("Begin Trackball tracking");
}


/*********************Main Loop*************************/
void loop() {
  
  //Wait for 2ms on each direction pin for movement.
  //Pins are driven HIGH by the breakout board.
  //pulseIn measures the length of each pulse in microseconds. 
  mouse_Lft = pulseIn(Lft, HIGH, 20000);
  mouse_Rht = pulseIn(Rht, HIGH, 20000);
  mouse_Up = pulseIn(Up, HIGH, 20000);
  mouse_Dwn = pulseIn(Dwn, HIGH, 20000);
  
  //Determine if there was movement in any direction. 
  //If movement occurred, adjust x/y coordinates based on movements.
  //Directionality is based off of an x/y plane (i.e., Up 1 unit and Right 1 unit = (1,1))
  if (mouse_Lft > 0)
  {
    x_position= --x_position;
  }
  if (mouse_Rht > 0)
  {
    x_position= ++x_position;
  }
  if (mouse_Up > 0)
  {
    y_position= ++y_position;
  }
  if (mouse_Dwn > 0)
  {
    y_position= --y_position;
  }
  
  //Output x/y coordinates to Serial terminal
  Serial.print("Trackball Position: \t X-Position= ");  
  Serial.print(x_position);
  Serial.print(" \t Y-position= ");
  Serial.print(y_position);
  Serial.println();
  
  //Check for button click. If present, print to Serial monitor.
  buttonClick = digitalRead(Btn);
  if (buttonClick == LOW)
  {
    Serial.println("Click");  
  }
}

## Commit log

2014-10-14 Initial Commit
    initial commit with brd/sch
    [Blackberry_Trackballer_Breakout.brd, Blackberry_Trackballer_Breakout.sch]
2014-10-29 0603, sch update, top layer
    Updated all components to 0603
    Updated the sche to frame letter
    added rev code
    made second pcb to secure the trackball and rid the pcb of glue.
    [Blackberry_Trackballer_Breakout.brd, Blackberry_Trackballer_Breakout.sch]
2014-12-08 initial qc checklist changes.
    [Blackberry_Trackballer_Breakout.brd, Blackberry_Trackballer_Breakout.sch]
2014-12-10 Schematic Clean up, added Blackberry device...
    and trace re routes.
    [Blackberry_Trackballer_Breakout.brd, Blackberry_Trackballer_Breakout.sch]
2014-12-10 Added attributes to swch, trackball and whte led
    [Blackberry_Trackballer_Breakout.brd, Blackberry_Trackballer_Breakout.sch]
2014-12-10 Initial commit of the brd/sch files.
    [Blackberry_Trackballer_MountingPCB.brd, Blackberry_Trackballer_MountingPCB.sch]
2014-12-10 Added version #
    [Blackberry_Trackballer_MountingPCB.brd]
2014-12-10 Added vcc range to sch
    [Blackberry_Trackballer_Breakout.sch]
2014-12-15 created panel v13
    [Blackberry_Trackballer_Breakout_Panel_v13.brd]
2014-12-16 Fixed silk error
    [Blackberry_Trackballer_MountingPCB.brd, Blackberry_Trackballer_MountingPCB.sch]
2015-03-05 Updating file names, directory names to prevent issues on different OS
    [Blackberry_Trackballer_Breakout_Panel_v13.brd, SparkFun_Blackberry_Trackballer_Breakout.brd, SparkFun_Blackberry_Trackballer_Breakout.sch]
2015-03-16 Testing Interrupt code/hookup
2015-03-16 Testing digitalPinToInterrupt-Does not work
    [SparkFun_BlackBerry_Trackballer_Breakout_Demo.ino]
2015-03-16 Fixing pin connections

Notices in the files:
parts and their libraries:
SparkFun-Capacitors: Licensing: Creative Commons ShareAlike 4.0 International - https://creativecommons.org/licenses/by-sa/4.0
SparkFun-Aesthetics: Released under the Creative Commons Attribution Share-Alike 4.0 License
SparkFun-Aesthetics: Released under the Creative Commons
